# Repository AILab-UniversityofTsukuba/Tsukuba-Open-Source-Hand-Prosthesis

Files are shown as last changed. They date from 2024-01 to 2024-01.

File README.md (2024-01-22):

# Tsukuba-Hand-Prosthesis-Open-Source

Currently, myoelectric hand prostheses present physical and control challenges that hinder their effective use by children with unilateral congenital below-elbow deficiency (UCBED).
In the Artificial Intelligence Laboratory at the University of Tsukuba, we conducted an investigation to address some of these challenges. 
Regarding the physical challenges, we focused on excessive weight, lack of hand size adaptability, and lack of socket size adaptability.
As for the control challenges, our focus was on the uncertain EMG measurement, absence of sensory feedback, and challenging EMG training.

To find clinically feasible solutions for these challenges, we proposed developing a myoelectric hand prosthesis for children with UCBED under personalized and modular design approaches.
We proposed a personalized approach to involve children in the design process, finding out and meeting the children’s unique needs regarding myoelectric prosthetic hands to facilitate its adoption.
While, we adopted a modular approach to divide the prosthesis into interchangeable modules, providing flexibility to update the modules to adapt to children's developmental growth.
Both approaches were applied to all levels of the design of the prosthesis.

Results show that the developed myoelectric prosthesis presents potential solutions for the mentioned challenges.
As an outcome of the study and synthesis of the personalized and modular design approaches, the developed hand prosthesis, including the proposed solutions, are shared as open-source material. 
Thus, children have free access to a myoelectric hand prosthesis that can be customized to suit their evolving growth patterns and personal preferences.
Furthermore, thanks to their modularity, the prosthesis's modules can be interchanged and used with other prostheses, such as controlling a specific-activity prosthesis while using our proposed prosthesis interface.



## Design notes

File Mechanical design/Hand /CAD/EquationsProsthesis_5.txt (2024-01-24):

"HandL"= 100mm
"PalmBreadth"= round ( "HandL" * 0.45 , 1 )
"PalmPalmarL"= round ( "HandL" * 0.58 , 1 )
"PalmDorsalL"= round ( "HandL" * 0.52 , 1 )
"MiddleFPalmarL"= round ( "HandL" * 0.42 , 1 )
"MiddleFDorsalL"= round ( "HandL" * 0.48 , 1 )
"ThumbFL" = round ( "MiddleFDorsalL" * 0.64 , 1 )
"IndexFL" = round ( "MiddleFDorsalL" * 0.91 , 1 )
"RingFL" = round ( "MiddleFDorsalL" * 0.94 , 1 )
"LittleFL" = round ( "MiddleFDorsalL" * 0.73 , 1 )
"PalmThickness"= 27.5mm + round ( 2 * ( "HandL" - 100 ) * 0.01 , 1 )
"Thicknesss" = round ( 2 + ( "HandL" - 100 ) * 0.01 , 1 )
"WristBreadth"= round ( "PalmBreadth" * 0.9 , 1 )
"MiddleFD"= round ( "MiddleFDorsalL" * 0.22 + 1 , 1 )
"ThumbFD"= round ( "MiddleFD" + 2 , 1 )
"IndexFD"= round ( "MiddleFD" , 1 )
"RingFD"= round ( "MiddleFD" - 1 , 1 )
"LittleFD" = round ( "MiddleFD" - 2 , 1 )
"FDBreadth" = round ( ( "PalmBreadth" + 3 ) / 4 , 1 )
"IndexFC"= round ( "PalmBreadth" / 2 - "FDBreadth" / 2 , 1 )
"MiddleFC"= round ( "PalmBreadth" / 2 - "FDBreadth" * 3 / 2 , 1 )
"RingFC" = round ( "PalmBreadth" / 2 - ( "FDBreadth" * 3 - 5 ) / 2 , 1 )
"LittleFC"= round ( "PalmBreadth" / 2 - ( "FDBreadth" - 2 ) / 2 , 1 )
"PIPAngle"= 30deg
"DIPAngle"= 15deg
"PrintingTolerance"= 0.2mm
"RotationAxisD"= 5mm

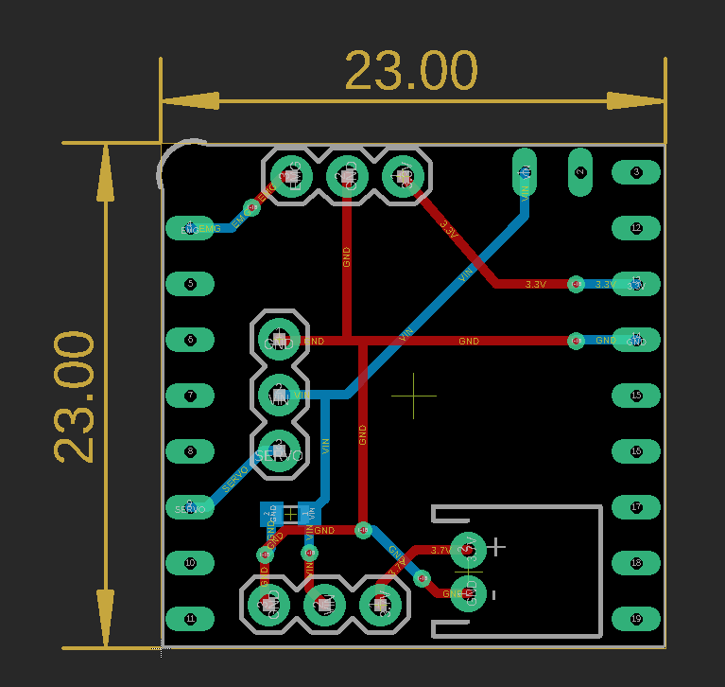
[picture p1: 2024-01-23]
Electronics/PCB/Control board/Control board .png

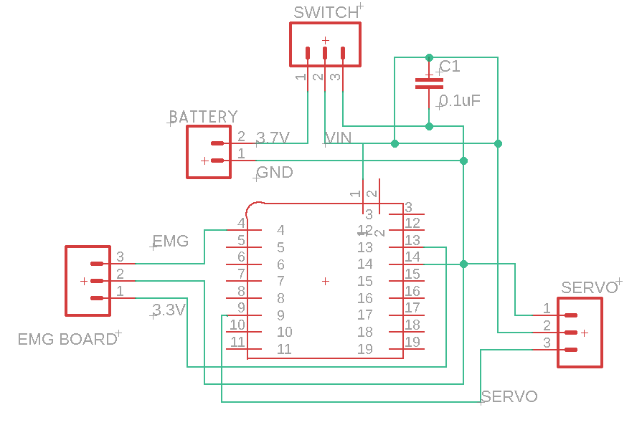
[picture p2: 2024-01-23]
Electronics/PCB/Control board/Control schematics.png

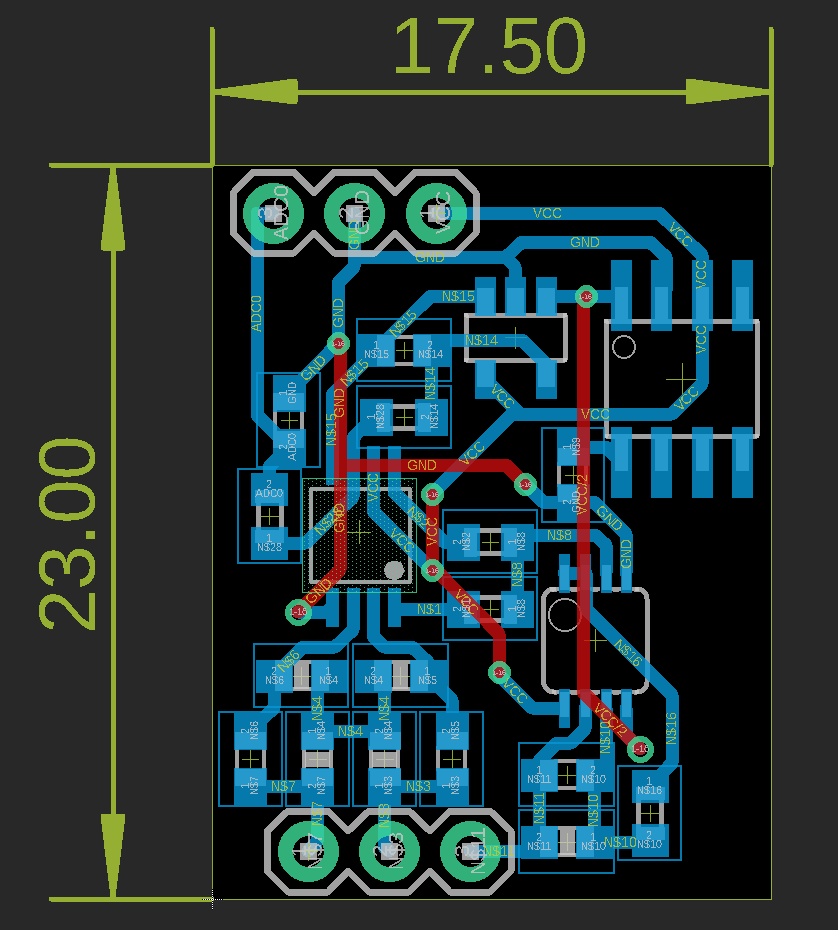
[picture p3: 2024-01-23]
Electronics/PCB/EMG board/EMG board.png

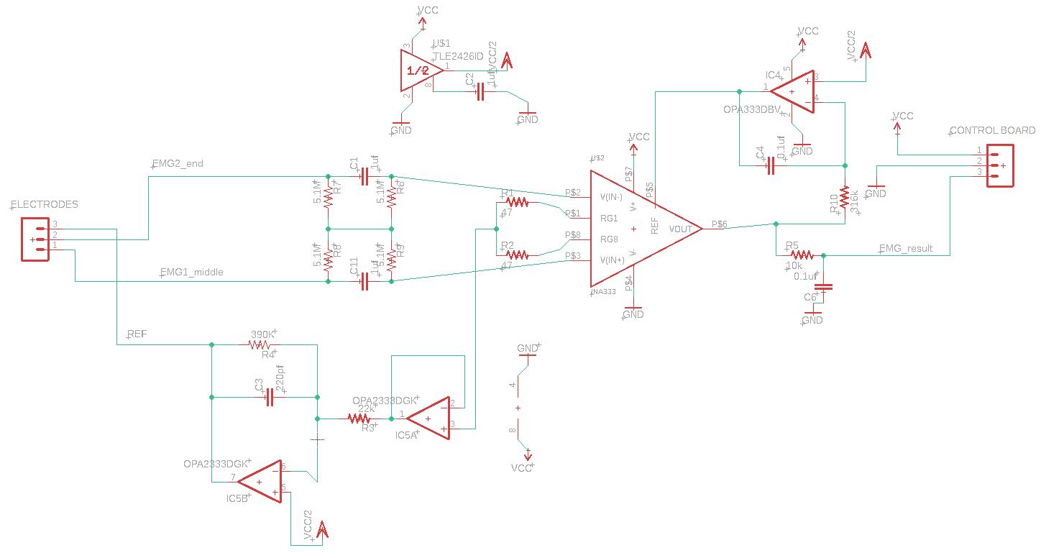
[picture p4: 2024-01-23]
Electronics/PCB/EMG board/EMG schematics.png

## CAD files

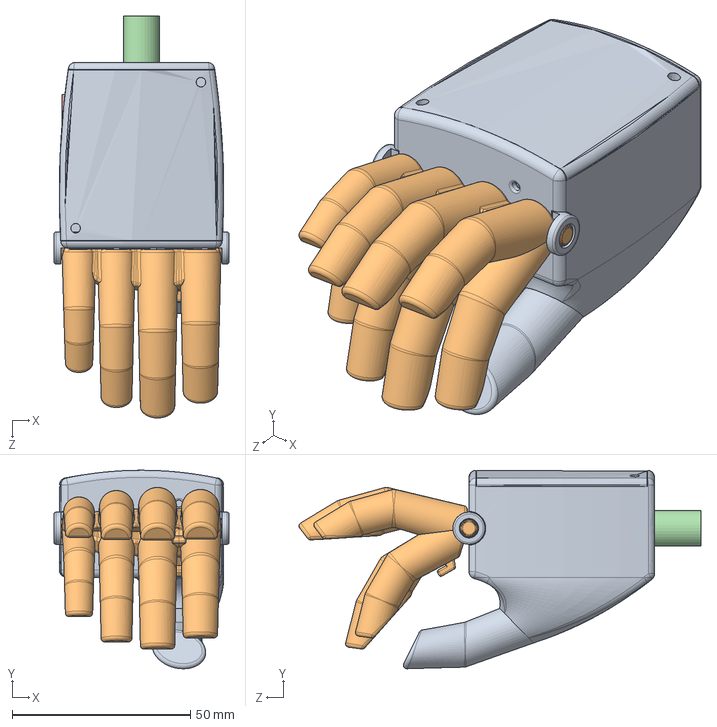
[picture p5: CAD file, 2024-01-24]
Mechanical design/Hand /CAD/HandProsthesis_5.SLDASM
49.0 x 55.6 x 112.6 mm
Palm_structure_5
Fingers_3dPrint_5

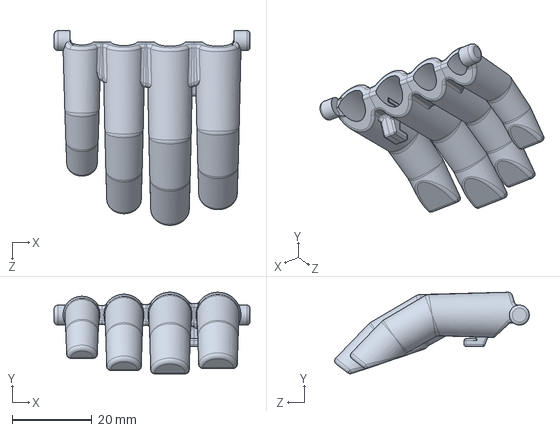
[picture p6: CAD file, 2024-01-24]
Mechanical design/Hand /CAD/Fingers_3dPrint_5.SLDPRT
49.0 x 20.4 x 48.7 mm

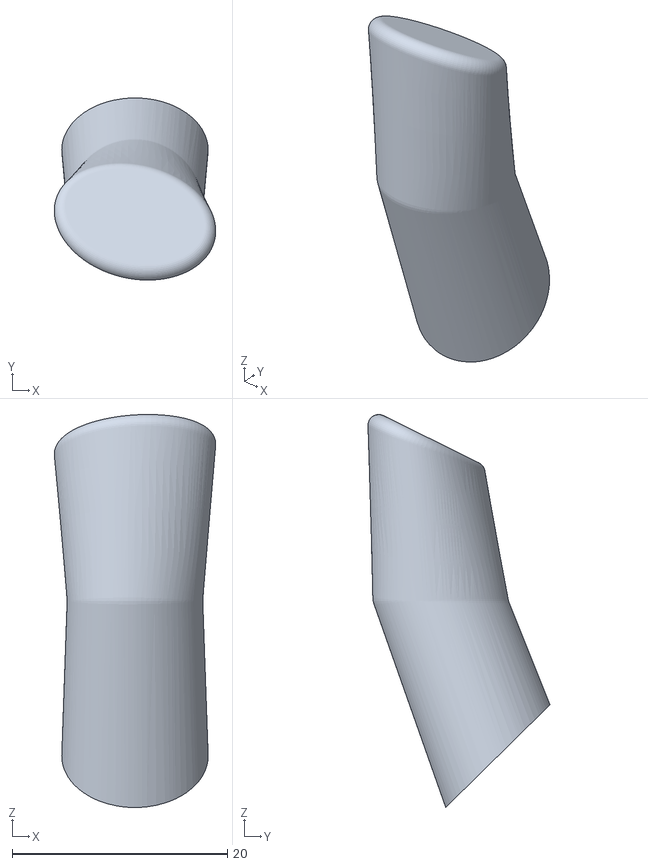
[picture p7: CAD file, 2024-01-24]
Mechanical design/Hand /STL/100_R/Thumb - 100_R.STL
15.0 x 16.9 x 36.5

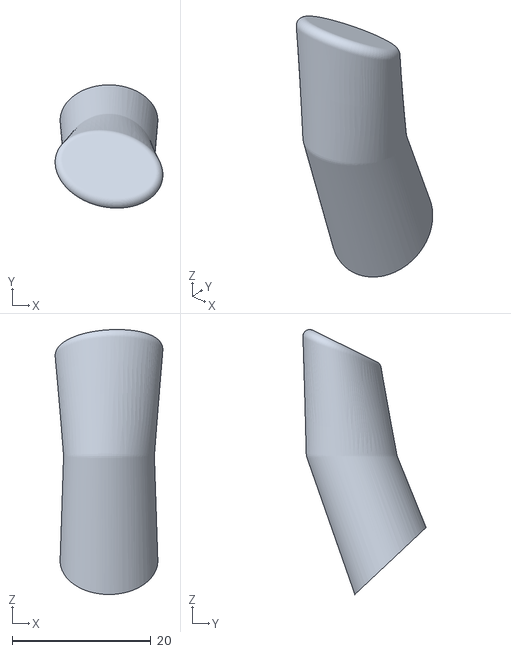
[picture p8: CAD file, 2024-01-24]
Mechanical design/Hand /STL/105_R/Thumb - 105_R.STL
15.5 x 17.8 x 38.2

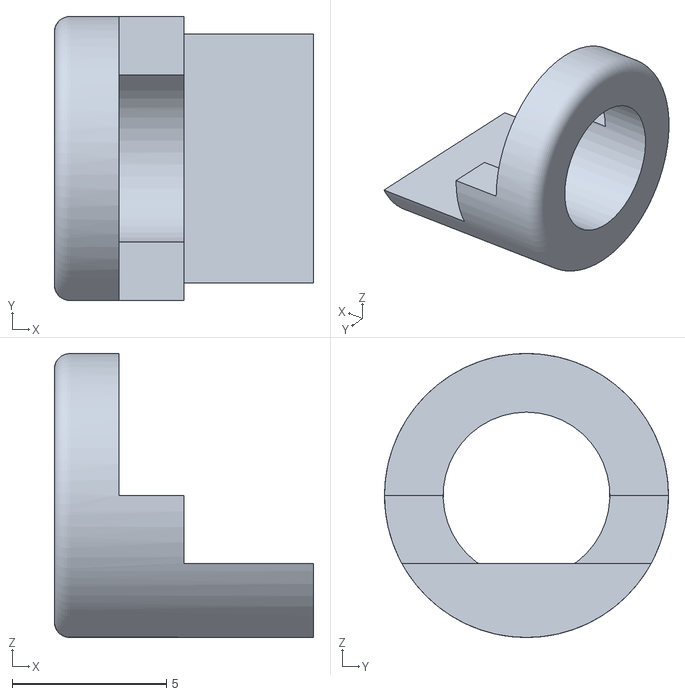
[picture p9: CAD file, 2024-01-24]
Mechanical design/Hand /STL/110_R/Rotation axis - 110_R.STL
8.40 x 9.20 x 9.20

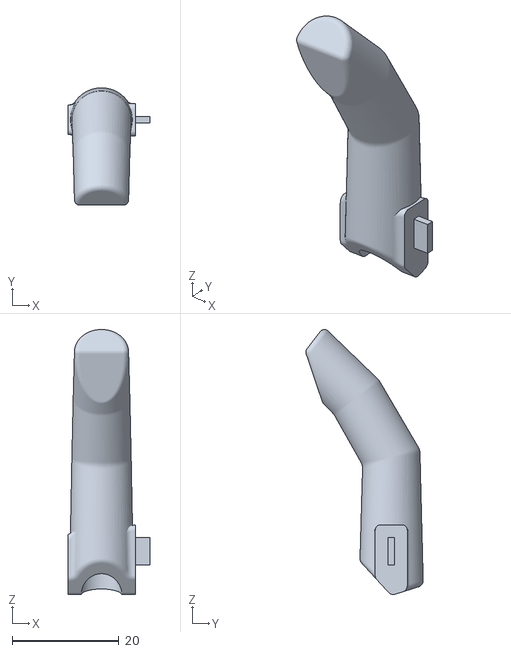
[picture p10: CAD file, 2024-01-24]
Mechanical design/Hand /STL/115_R/Ring finger - 115_R.STL
15.4 x 22.0 x 49.6

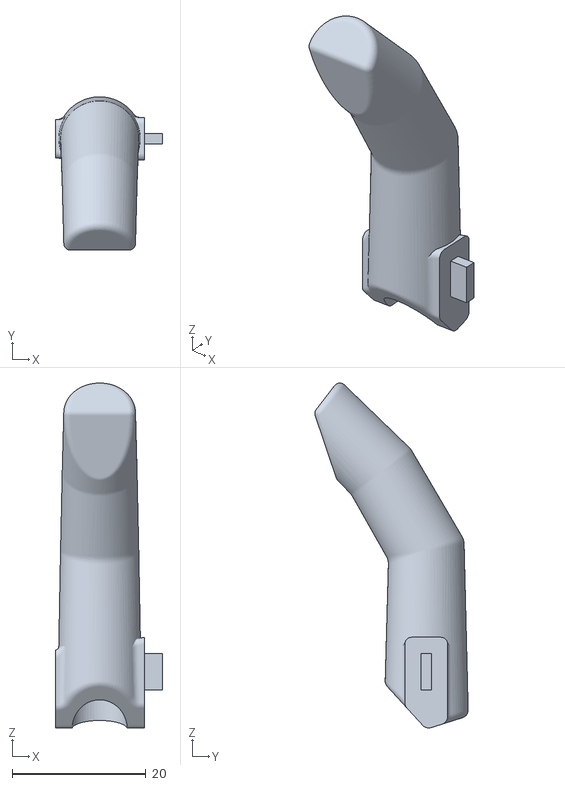
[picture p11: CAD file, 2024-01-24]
Mechanical design/Hand /STL/120_R/Ring finger - 120_R.STL
16.0 x 22.9 x 51.6

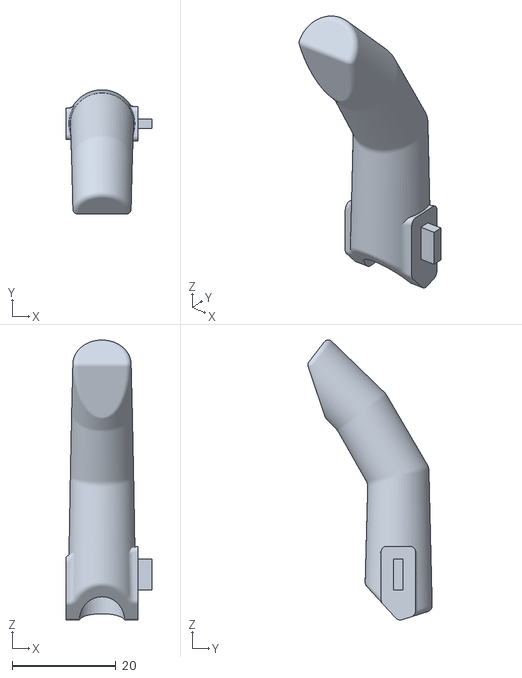
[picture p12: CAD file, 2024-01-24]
Mechanical design/Hand /STL/125_R/Ring finger - 125_R.STL
16.5 x 24.0 x 53.9

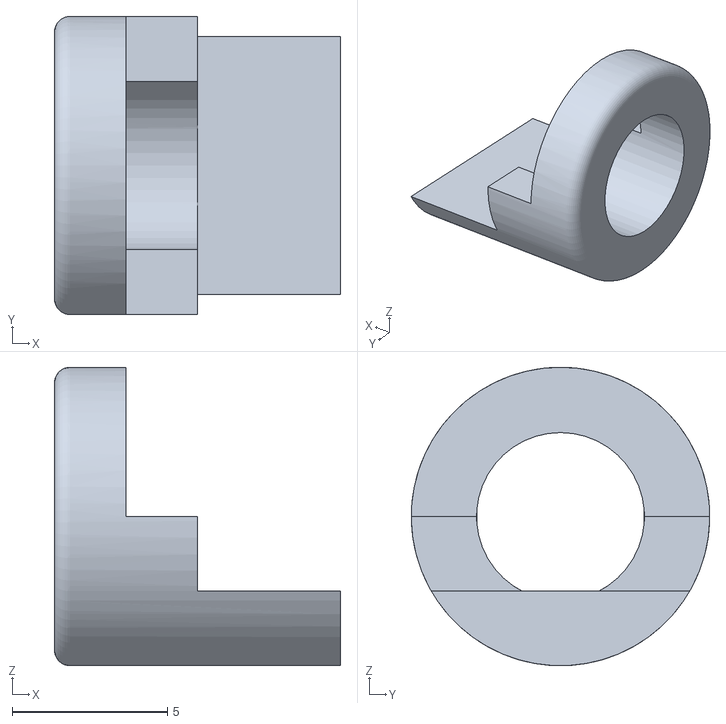
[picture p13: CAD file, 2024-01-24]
Mechanical design/Hand /STL/130_R/Rotation axis - 130_R.STL
9.20 x 9.60 x 9.60

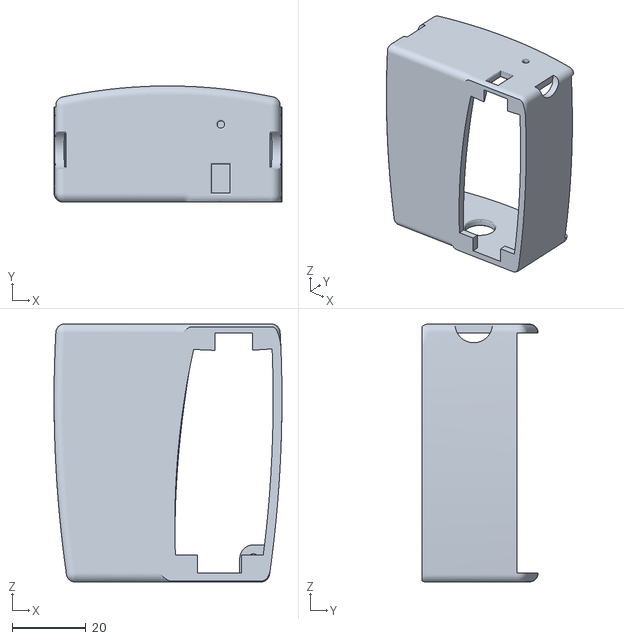
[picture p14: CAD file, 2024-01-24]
Mechanical design/Hand /STL/135_R/Palm - 135_R.STL
62.0 x 31.6 x 70.2

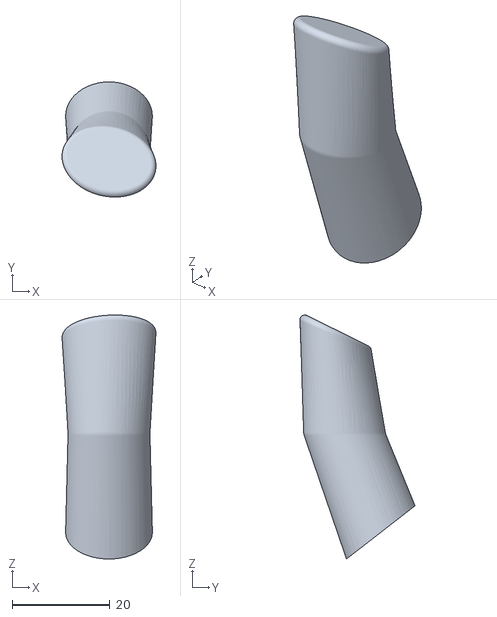
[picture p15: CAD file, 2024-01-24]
Mechanical design/Hand /STL/140_R/Thumb - 140_R.STL
19.3 x 23.6 x 50.0

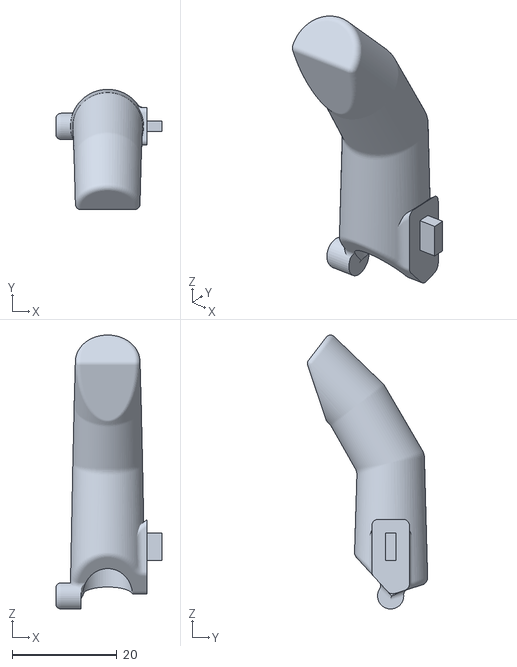
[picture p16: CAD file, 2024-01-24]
Mechanical design/Hand /STL/145_R/Little finger - 145_R.STL
20.3 x 22.9 x 52.3

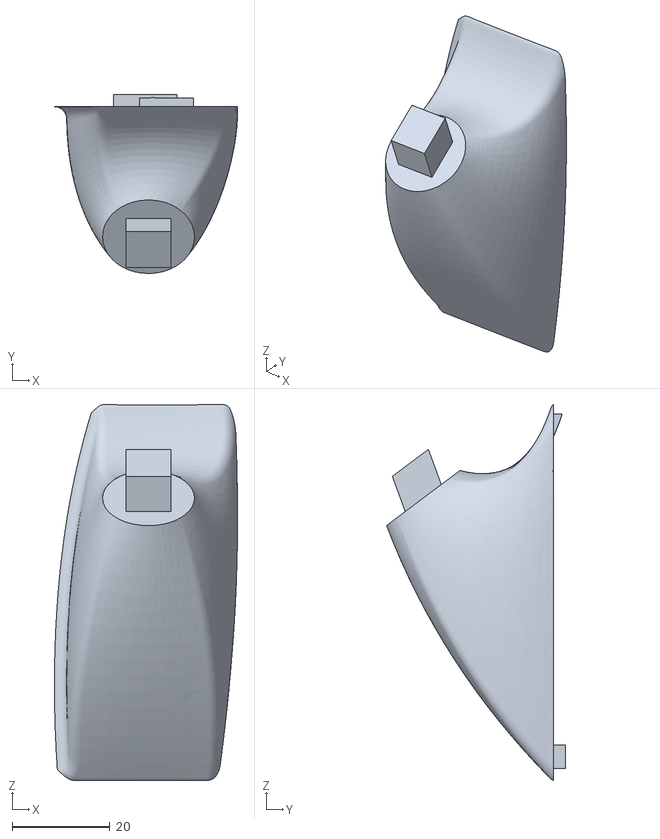
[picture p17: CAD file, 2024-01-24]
Mechanical design/Hand /STL/150_R/Thenar eminence - 150_R.STL
37.5 x 36.6 x 77.0

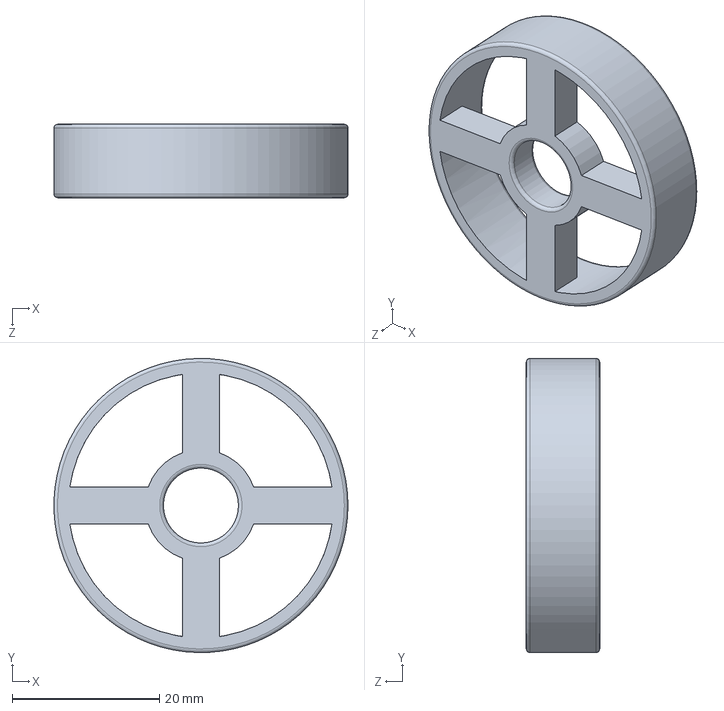
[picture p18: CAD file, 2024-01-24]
Mechanical design/Wrist rotation mechanism/CAD/Socket_connector.SLDPRT
40.0 x 40.0 x 10.0 mm

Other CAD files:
Mechanical design/Wrist rotation mechanism/STL/Socket Connector - D_30.STL
Mechanical design/Hand /STL/100_R/Thenar eminence - 100_R.STL
Mechanical design/Hand /STL/105_R/Rotation axis - 105_R.STL
Mechanical design/Hand /STL/110_R/Ring finger - 110_R.STL
Mechanical design/Hand /CAD/Palm_structure_5.SLDPRT
Mechanical design/Hand /STL/100_R/Index finger - 100_R.STL
Mechanical design/Hand /STL/100_R/Lid - 100_R.STL
Mechanical design/Hand /STL/100_R/Little finger - 100_R.STL
Mechanical design/Hand /STL/100_R/Middle finger - 100_R.STL
Mechanical design/Hand /STL/100_R/Palm - 100_R.STL
Mechanical design/Hand /STL/100_R/Ring finger - 100_R.STL
Mechanical design/Hand /STL/100_R/Rotation axis - 100_R.STL
Mechanical design/Hand /STL/105_R/Index finger - 105_R.STL
Mechanical design/Hand /STL/105_R/Lid - 105_R.STL
Mechanical design/Hand /STL/105_R/Little finger - 105_R.STL
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

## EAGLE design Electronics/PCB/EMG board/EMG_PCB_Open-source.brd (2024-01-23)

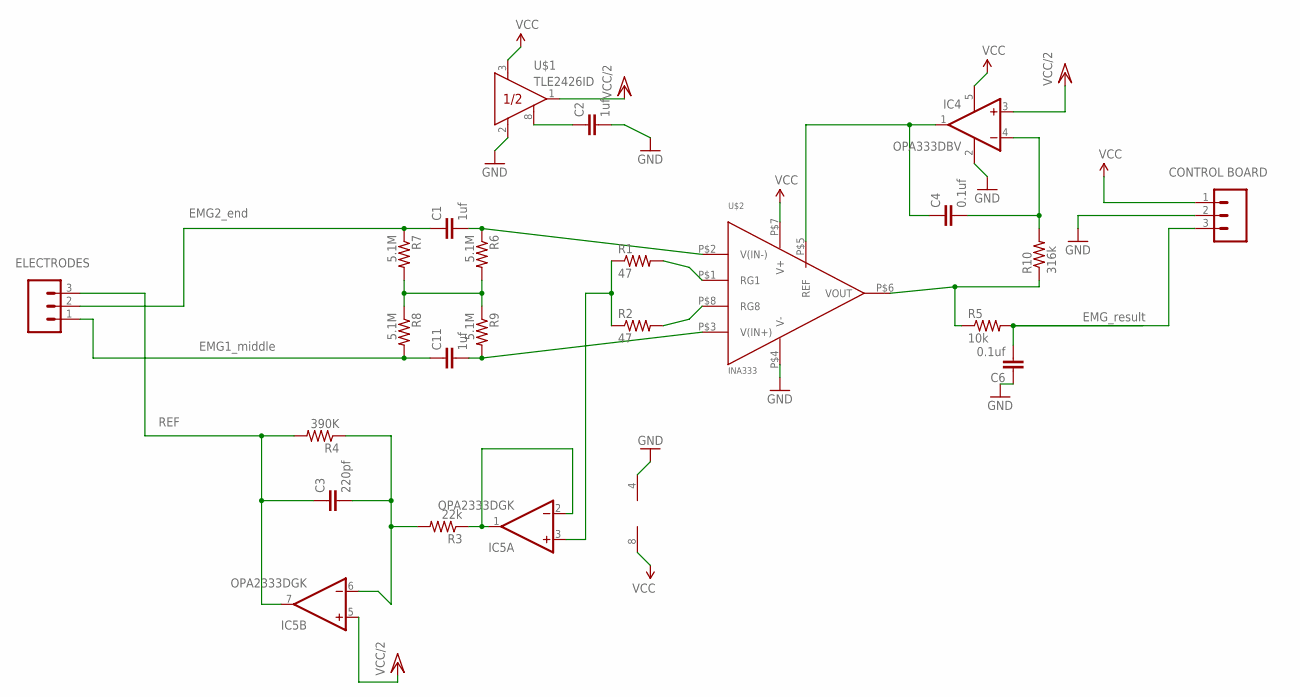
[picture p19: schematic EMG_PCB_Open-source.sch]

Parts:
C1, C2, C11: 1uf; C0603
C3: 220pf; C0603
C4, C6: 0.1uf; C0603
IC4: OPA333DBV; SOT23-5
IC5: OPA2333DGK; MSOP08
J1, J2: 455-1750-1-ND; 1X03
R1, R2: 47; R0603
R3: 22k; R0603
R4: 390K; 0603-RES
R5: 10k; R0603
R6, R7, R8, R9: 5.1M; 0603-RES
R10: 316k; R0603
U$1: TLE2426ID; SO-8
U$2: INA333; 8-MSOP

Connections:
ADC0: C6.2, J2.3, R5.2
GND: C2.2, C6.1, IC4.2 (V-), IC5.4 (V-), J2.2, U$1.2 (COM), U$2.P$4 (V-)
unnamed: R1.2, U$2.P$1 (RG1)
unnamed: R2.2, U$2.P$8 (RG8)
unnamed: C1.1, J1.2, R7.1
unnamed: R6.2, R7.2, R8.1, R9.1
unnamed: C1.2, R6.1, U$2.P$2 (V(IN-))
unnamed: C11.2, R9.2, U$2.P$3 (V(IN+))
unnamed: C11.1, J1.1, R8.2
unnamed: IC5.3 (+IN), R1.1, R2.1
unnamed: C2.1, U$1.8 (NR)
unnamed: C3.2, IC5.6 (-IN), R3.2, R4.1
unnamed: C3.1, IC5.7 (OUT), J1.3, R4.2
unnamed: C4.2, IC4.4 (-IN), R10.2
unnamed: C4.1, IC4.1 (OUT), U$2.P$5 (REF)
unnamed: IC5.1 (OUT), IC5.2 (-IN), R3.1
unnamed: R5.1, R10.1, U$2.P$6 (VOUT)
VCC: IC4.5 (V+), IC5.8 (V+), J2.1, U$1.3 (IN), U$2.P$7 (V+)
VCC/2: IC4.3 (+IN), IC5.5 (+IN), U$1.1 (OUT)

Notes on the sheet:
EMG2_end
EMG1_middle
REF
EMG_result
ELECTRODES
CONTROL BOARD

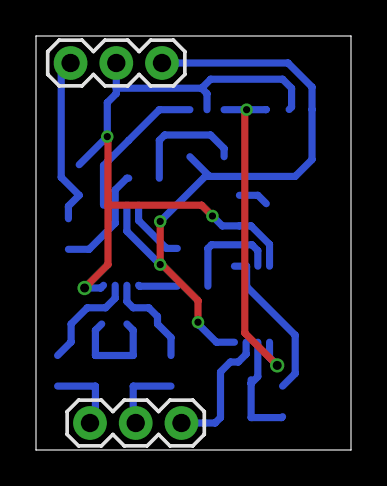
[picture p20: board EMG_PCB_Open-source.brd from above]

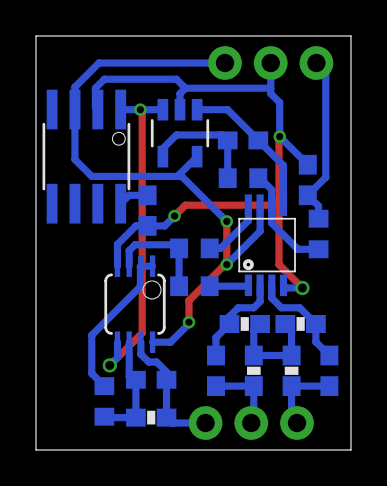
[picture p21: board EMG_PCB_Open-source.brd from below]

Board: 2 copper layers, 17.5 x 23.0 mm, 22 parts (20 on the bottom side), 19 nets.

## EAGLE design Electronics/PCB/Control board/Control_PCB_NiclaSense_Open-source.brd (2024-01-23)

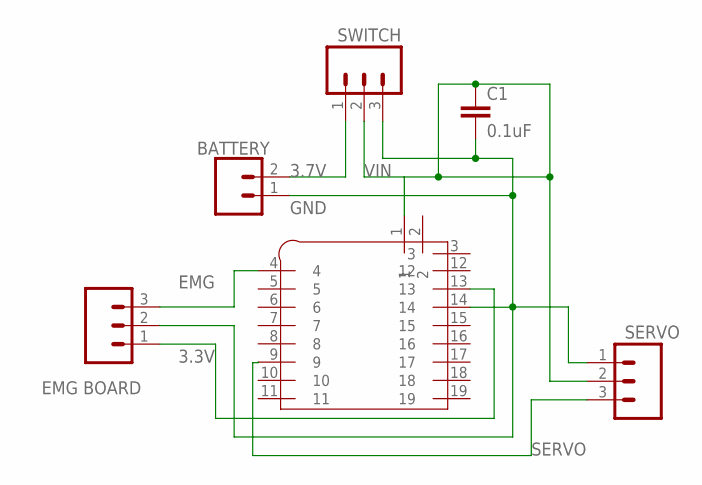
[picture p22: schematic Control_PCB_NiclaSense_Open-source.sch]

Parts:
BATTERY: CONN_02JST-PTH-2; JST-2-PTH
C1: 0.1uF; C0603K
J2, J3: 455-1750-1-ND; 1X03
SD: sadasd; 1X03
U$1: ARDUINO_NICLA

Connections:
3.3V: SD.1, U$1.13
3.7V: BATTERY.2, J3.1
EMG: SD.3, U$1.4
GND: BATTERY.1, C1.2, J2.1, J3.3, SD.2, U$1.14
SERVO: J2.3, U$1.9
VIN: C1.1, J2.2, J3.2, U$1.1

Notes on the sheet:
EMG BOARD
SERVO
SWITCH

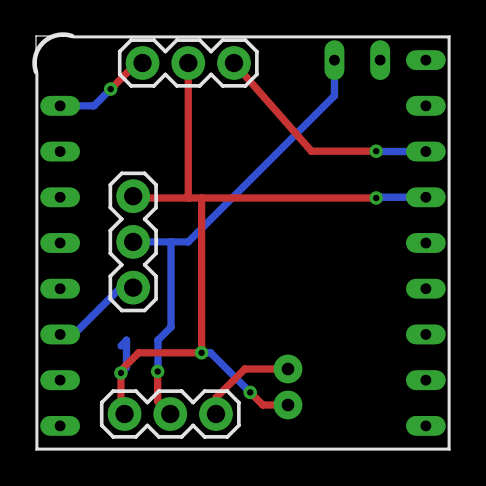
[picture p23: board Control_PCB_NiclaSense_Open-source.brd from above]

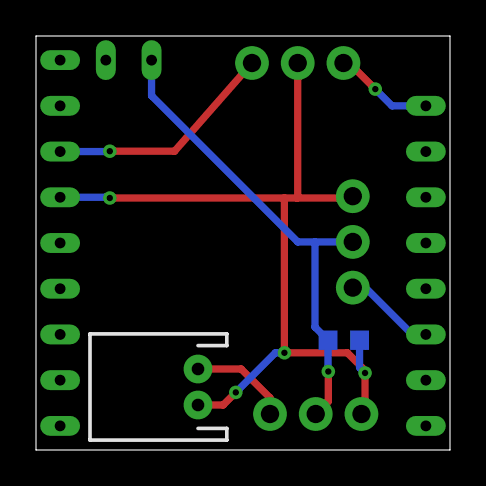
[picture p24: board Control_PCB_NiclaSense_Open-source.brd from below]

Board: 2 copper layers, 23.0 x 23.0 mm, 6 parts (2 on the bottom side), 6 nets.

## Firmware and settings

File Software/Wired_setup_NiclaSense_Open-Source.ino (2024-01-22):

/*Save the serial prints in case of a sudden malfunctioning!!! */

//This sketch is only for the Nicla Sense ME, not the Nicla Vision
#ifdef ARDUINO_NICLA_VISION
  #error "Run the standard Blink.ino sketch for the Nicla Vision"
#endif

#include "Filters.h"
#include <BasicLinearAlgebra.h>
#include <math.h>
#include <Servo.h>
#include "TickTwo.h" //For Arduino BLE nano 33, let's find other boards!

#define ARR_SIZE(m) (sizeof(m) / sizeof(m[0]))
#define WINDOW 50 //Windows size of 50 samples = 100ms
#define MAX_CHAR 32

//This sketch is only for the Nicla Sense ME, not the Nicla Vision
#ifdef ARDUINO_NICLA_VISION
  #error "Run the standard Blink.ino sketch for the Nicla Vision"
#endif

// Intialise library which communicates with RGB driver
// Functions accessible under 'nicla' namespace
#include "Nicla_System.h"    

/***EMG***/
Filter bandP0;
Filter notchF0;

//Emg0: Flexion and use the new one. Less gain(?)
//Emg1: Extension and ues the old one. Recognize more what is the weaker muscle. More gain(?)
int emg_inputpin = A0;
int emg_analog;
int gain;
float emg_bpf, emg_nf, emg_abs, emg_f, emg_ff; 
int threshold1, threshold2;
float array_emg[WINDOW];
bool servo_status, serial_status;
const int hand_open = 1900; //1900
const int hand_closed = 1100; //1100

//Serial read
char receivedChars[MAX_CHAR];
char command_parameter[MAX_CHAR];
int command_value = 0;

float sum;
int indexus;

float mavFilter(float in) {
    sum = sum - array_emg[indexus];
    array_emg[indexus] = in;
    sum = sum + array_emg[indexus];
    indexus++;
    if (indexus >= WINDOW) {
        indexus = 0;
    }
    return sum/WINDOW;
}

void initArrayEmg(void) {for(int i = 0; i < WINDOW; i++) {array_emg[i] = 0.0;}}

Servo hand_servo;

/***TickTwo***/
void analog_reading();
TickTwo timer1(analog_reading, 2, 0, MILLIS); //ticker 2ms, 0.002s, 500Hz. 
void servo_opening();
TickTwo timer2(servo_opening, 10, 0, MILLIS); //ticker 10ms, 0.01s, 100Hz. 
void serial_sending();
TickTwo timer3(serial_sending, 15, 0, MILLIS); //ticker 10ms, 0.01s, 100Hz. 

void setup() { // put your setup code here, to run once:

  //run this code once when Nicla Sense ME board turns on
  nicla::begin();               // initialise library
  nicla::leds.begin();          // Start I2C connection
  nicla::leds.setColor(red); 

  emg_analog = 0;
  emg_bpf = 0.0;
  emg_nf = 0.0;
  emg_abs = 0.0;
  emg_f = 0.0;
  emg_ff = 0.0;
  sum = 0.0;
  indexus = 0;
  threshold1 = 100;
  threshold2 = 100;
  gain = 1;
  initArrayEmg();
  //f0 = 55 Hz, Q = 0.42  
  //LETS, IMPROVE THIS TO: 20-150 HZ!!!
  bandP0.bandPass(84, 1.76, 500); //1.76, 0.77, 45-154. 10 difference from the high spectrum
  notchF0.notchF(50, 0.2, 500); //0.2, 7.2, 46.648-53.593
  servo_status = false;
  serial_status = false;

  hand_servo.attach(0);
  hand_servo.writeMicroseconds(hand_closed);

  /***Serial***/
  Serial.begin(230400); //115200
  while (!Serial); // This means connection to the PC, if it is connected no matter the serial port is displayed, it will be True!!!
  delay(100);
  //nicla::leds.setColor(green); 

  /***TickTwo***/
  timer1.start();
  delay(100);
  timer2.start(); //Good to see when the prosthesis is opening while setting the thresholds! 
  delay(100);
}

void loop() {
  timer1.update();
  timer2.update();  
  if ((Serial) && (serial_status == false)){ //Enter only when the microcontroller is connected to the computer
    serial_status = true;
    timer3.start();
    //nicla::leds.setColor(cyan); 
    }
  else if ((Serial) && (serial_status == true)){ //Enter only when the microcontroller is connected to the computer
    //nicla::leds.setColor(green); 
    timer3.update();
  }
  else if ((!Serial) && (serial_status == true)){
    //nicla::leds.setColor(off); 
    timer3.stop();
    serial_status = false;
  }
  else {
  }
}

void analog_reading(){
  emg_analog = analogRead(emg_inputpin);
  emg_bpf = bandP0.process(emg_analog); 
  emg_nf = notchF0.process(emg_bpf);
  emg_abs = abs(emg_nf); 
  emg_f = mavFilter(emg_abs);
  emg_ff = emg_f*gain;
}

//Open the servomotor
void servo_opening(){
  if (emg_ff > threshold1){
    servo_status = true;
    hand_servo.writeMicroseconds(hand_open);
  } 
  else if ((emg_ff > threshold2)&&(servo_status == true)){
    hand_servo.writeMicroseconds(hand_open);
  }
  else{
    servo_status = false;
    hand_servo.writeMicroseconds(hand_closed);
  }
}

void serial_sending(){
  //Plot the data all the the time that the serial port is connected.
  Serial.print(emg_ff);
  Serial.print(",");
  Serial.print(threshold1);
  Serial.print(",");
  Serial.println(threshold2);
  
  //Read the data when there a data is sent written from the serial command/plotter.
  if(Serial.available() > 0){
    for (int i = 0; i < MAX_CHAR; i++) {receivedChars[i] = 0;}
    Serial.readBytesUntil('\n', receivedChars, 32);
    //Split the data into parts.
    char* strtokIndx; 
    strtokIndx = strtok(receivedChars,"=");      // get the first part - the string
    strcpy(command_parameter, strtokIndx); // copy it to messageFromPC
    strtokIndx = strtok(NULL,"=");      // get the first part - the string
    command_value = atoi(strtokIndx); // copy it to messageFromPC
    if (strcmp(command_parameter, "t1") == 0){ //True
      threshold1 = command_value; 
    }
    else if(strcmp(command_parameter, "t2") == 0) {
      threshold2 = command_value;
    }
    else if(strcmp(command_parameter, "g") == 0) {
      gain = command_value;
    }
    else{}
  }
}

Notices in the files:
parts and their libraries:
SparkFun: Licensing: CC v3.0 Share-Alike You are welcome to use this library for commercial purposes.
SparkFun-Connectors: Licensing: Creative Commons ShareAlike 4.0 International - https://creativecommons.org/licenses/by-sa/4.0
